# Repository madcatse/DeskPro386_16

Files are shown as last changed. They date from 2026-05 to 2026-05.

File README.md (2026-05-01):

# DeskPro386_16
Compaq DeskPro 386/16 KiCad Schematic and PLD files

The Compaq DeskPro 386 was one of the first 80386/i386 PC Compatable computers.
It used mainly standard components found in the PC and PC-XT and used 14 
basic 20 and 24 pin Programmable Logic Devices (PLDS).
Later DeskPro 386 versions used VLSI 160+ pin chips unsuitable for use with breadboards.

Internal Compaq Design documents have been made available on Archive.org which
not only include more recent schematics than the original DeskPro 386/16 Technical Guide,
but also include the PLD Logic Rules and test vectors for all the chips in the PALASM language.

PALASM can be converted into CUPL for use with WinCUPL/II and modern ATF16V8B and ATF22V10C PLDs.

Compaq DeskPro 386/16 Technical Guide https://archive.org/details/compaq-desk-pro-386-technical-reference-guide-vol-1-1986-09
COmpaq DeskPro 386/16 Internal Design Document https://archive.org/details/compaq-desk-pro-386-technical-reference-guide-vol-1-1986-09

## KiCad Schematics
The Internal Design Document schematics have been reproduced in KiCad 10.
I have layed them out in one big diagram so that related pages are closer together to make tracing labels easier.
I find decomposed diagrams over many pages more difficult to understand.
Feel free to make a copy and re-organise if you feel differently.

Many of the chip symbols have been created to match the DeskPro schematics (DP in name) in the Breadboarding Symbol library (Breadboarding.kicad_sym).
You will need to configure the path to this library after opening the Project.

Use Preferences | Manage Symbol Libraries... then select the "Project Specific Libraries" tab
Select the path to the Breadboarding.kicad_sym file downloaded from GitHub.

Note many of the DP symbols have the power pins removed as this is what the DeskPro schematics did.
If you try to use these symbols for making a PCB be aware of the missing power pins and decoupling capacitors.

Symbols with BB in the name tend to match the physical pin layout so that the schematic can also be used for laying out breadboard designs.
The layout dimensions are very large (almost twice as big as A0 paper size) at 40" x 70".
PDF readers may have problems dealing with the schematic.

## Programmable Logic Definitions
There are two versions of the Internal Design Document, text mode and photo mode.
Generally I have used text mode to convert the content but sometimes photo mode is better.
The main issues in converting the logic definitions have been confusions between numeric 0 and letter O and letter l and numeric 1.
The test vectors have required quite a lot of massaging as PDF does not make it easy to copy the content due to it sometimes arranging text blocks in columns.
The PALASM folder has the text copies of the original PDF document in their original format (and with original typos and spelling mistakes).
The file extension .ASM is used as this is the recognised file extension for the CUPL 2.0 PTOC.EXE converter which converts PLDASM files into a .PLD logic definition and .SI simulation file.

THe ZIP file Logical_Devices_CUPL_v3.2b.zip contains an old version of CUPL (July 1990) which predates ATMEL/MicroChip and include the PTOC.EXE utility used to convert PALASM in CUPL format files.

More folders will be added with the .PLD logic definition and .SI simulation files as these are migrated and tested.

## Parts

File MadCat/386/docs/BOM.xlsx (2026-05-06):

Reference | Qty | Value | Аналог | Footprint | Datasheet
Конденсаторы
C100 | 1 | 10pF
C117 | 1 | 18pF
C1,C2,C60,C114 | 4 | 47pF
C97 | 1 | 0.001uF
C98,C101 | 2 | 0.047uF
C9,C19 | 2 | 10uF
Резисторы
R34,R35 | 2 | 22R
R8,R25,R26 | 3 | 30R
MRB4,RB4 | 2 | 33R |  | Resistor_THT:R_Array_SIP9 | http://www.vishay.com/docs/31509/csc.pdf
MRP1 | 1 | 33R
R37 | 1 | 51R
R44 | 1 | 60R
R31,R33,R36,R38 | 4 | 68R
R10,R13,R18,R28/9,R30,R42 | 6 | 180R
R3 | 1 | 270R
R5,R12,R16,R20,R21,R24 | 6 | 1K
MRP5,MRP7,MRP8,MRP9 | 4 | 4K7 |  | Resistor_THT:R_Array_SIP10 | http://www.vishay.com/docs/31509/csc.pdf
R4 | 1 | 4K7
MRP6 | 1 | 8K2 |  | Resistor_THT:R_Array_SIP11 | http://www.vishay.com/docs/31509/csc.pdf
R15,R22 | 2 | 8K2
RP3,RP4,RP5 | 3 | 8K2 |  | Resistor_THT:R_Array_SIP10 | http://www.vishay.com/docs/31509/csc.pdf
RP6,RP8 | 2 | 8K2 |  | Resistor_THT:R_Array_SIP9 | http://www.vishay.com/docs/31509/csc.pdf
R39,R40 | 2 | 10K
R14,R41,R999,R1000,RX1,RX2 | 6 | 20K
RP7 | 1 | 20K |  | Resistor_THT:R_Array_SIP10 | http://www.vishay.com/docs/31509/csc.pdf
R1 | 1 | 87K
R19 | 1 | 470K
R17 | 1 | 22M
R2 | 1 | 48K
Микросхемы
MU25,U71 | 2 | 74F00 | КР1531ЛА3 (https://radio-hobby.org/modules/analog/%D0%BA%D1%801531%D0%BB%D0%B03) |  | http://www.ti.com/lit/gpn/sn74ls00
MU9 | 1 | 74F04 | КР1531ЛН1 (https://radio-hobby.org/modules/analog/%D0%BA%D1%801531%D0%BB%D0%BD1) |  | http://www.ti.com/lit/gpn/sn74LS04
U73 | 1 | 74F08 | КР1531ЛИ1 |  | http://www.ti.com/lit/gpn/sn74LS08
U92 | 1 | 74F11 | КР1531ЛИ3 (https://radio-hobby.org/modules/analog/%D0%BA%D1%801531%D0%BB%D0%B83) |  | http://www.ti.com/lit/gpn/sn74LS11
MU3,MU19,MU24,MU50 | 4 | 74F32 | КР1531ЛЛ1 (https://radio-hobby.org/modules/analog/%D0%BA%D1%801531%D0%BB%D0%BB1) |  | http://www.ti.com/lit/gpn/sn74LS32
U69 | 1 | 74F74 | КР1531ТМ2 (https://radio-hobby.org/modules/analog/%D0%BA%D1%801531%D1%82%D0%BC2) | Package_DIP:DIP-28_W15.24mm | 74xx/74hc_hct74.pdf
U84 | 1 | 74F74BB | КР1531ТМ2 (https://radio-hobby.org/modules/analog/%D0%BA%D1%801531%D1%82%D0%BC2) |  | 74xx/74hc_hct74.pdf
MU2,U79,U82,U83 | 4 | 74F74 | КР1531ТМ2 (https://radio-hobby.org/modules/analog/%D0%BA%D1%801531%D1%82%D0%BC2) |  | 74xx/74hc_hct74.pdf
U12,U13,U14,U15,U112 | 5 | 2764 |  | Package_DIP:DIP-28_W15.24mm | http://ww1.microchip.com/downloads/en/DeviceDoc/11107M.pdf
U86 | 1 | 4069 | 1561ЛН4 (https://radio-hobby.org/modules/analog/1561%D0%BB%D0%BD4) |  | http://www.intersil.com/content/dam/Intersil/documents/cd40/cd4069ubms.pdf
U78 | 1 | 8042
U22,U23 | 2 | 8237A |  | Package_DIP:DIP-40_W15.24mm
U44,U45 | 2 | 8254 |  | Package_DIP:DIP-24_W15.24mm | http://www.scs.stanford.edu/10wi-cs140/pintos/specs/8254.pdf
MU15,MU16,MU17 | 3 | 74F158 | 1531КП18 (https://radio-hobby.org/modules/analog/1531%D0%BA%D0%BF18) |  | http://www.ti.com/lit/gpn/sn74LS158
MU21,MU74,U65,U74 | 4 | 74F175 | КР1531ТМ8 (https://radio-hobby.org/modules/analog/%D0%BA%D1%801531%D1%82%D0%BC8) |  | 74xx/74hc_hct74.pdf
U89 | 1 | 74F175BB | КР1531ТМ8 (https://radio-hobby.org/modules/analog/%D0%BA%D1%801531%D1%82%D0%BC8) |  | 74xx/74hc_hct74.pdf
U59 | 1 | 74F257BB | КР1531КП11 (https://radio-hobby.org/modules/analog/%D0%BA%D1%801531%D0%BA%D0%BF11) |  | http://www.ti.com/lit/gpn/sn74LS257
MU5,MU13 | 2 | 74F521 | КР1531СП2
MU11,MU12 | 2 | 74F573 |  |  | http://www.ti.com/lit/gpn/sn74LS573
MU26,MU30,MU36,MU42 | 4 | 74F657
MU31 | 1 | 51256-10 |  | Package_DIP:DIP-16_W7.62mm | https://minuszerodegrees.net/memory/41256/datasheet_HM50256.pdf
U54,U66 | 2 | 74ALS00 |  |  | http://www.ti.com/lit/gpn/sn74ls00
U88 | 1 | 74ALS02 |  |  | http://www.ti.com/lit/gpn/sn74ls02
U55 | 1 | 74ALS04 |  |  | http://www.ti.com/lit/gpn/sn74LS04
MU10,U53 | 2 | 74ALS08 |  |  | http://www.ti.com/lit/gpn/sn74LS08
MU1,MU8,U7,U61,U63,U67,U70,U72,U81,U90 | 10 | 74ALS74 |  |  | 74xx/74hc_hct74.pdf
U16 | 1 | 74ALS163 |  |  | http://www.ti.com/lit/gpn/sn74LS163
MU6,MU14,U9,U11,U19,U21,U24,U25,U34,U35 | 10 | 74ALS573 |  |  | http://www.ti.com/lit/gpn/sn74LS573
U91 | 1 | 74ALS1035 |  |  | www.ti.com/lit/ds/symlink/sn74ls07.pdf
MU22 | 1 | 74ALS29827DP
U75 | 1 | 74HC125 |  |  | http://www.ti.com/lit/gpn/sn74HC125
MU20,MU43 | 2 | 74LS20 |  |  | http://www.ti.com/lit/gpn/sn74LS20
U62 | 1 | 74LS51 |  |  | http://www.ti.com/lit/ds/symlink/sn74ls51.pdf
U47,U48 | 2 | 74LS125 |  |  | http://www.ti.com/lit/gpn/sn74LS125
U49 | 1 | 74LS138 |  |  | http://www.ti.com/lit/gpn/sn74LS138
U50 | 1 | 74LS175 |  |  | http://www.ti.com/lit/gpn/sn74LS175
U28 | 1 | 74LS243 |  |  | http://www.ti.com/lit/gpn/sn74LS243
MU54,U4,U26,U37,U40,U41,U51 | 7 | 74LS244 |  |  | http://www.ti.com/lit/ds/symlink/sn74ls244.pdf
U3,U8,U10,U17,U18,U20,U27,U33 | 8 | 74LS245 |  |  | http://www.ti.com/lit/gpn/sn74LS245
U57 | 1 | 74LS273 |  |  | http://www.ti.com/lit/gpn/sn74LS273
U5 | 1 | 74LS590 |  |  | http://www.ti.com/lit/gpn/sn74ls590
U30 | 1 | 74LS612 |  | Package_DIP:DIP-40_W15.24mm | http://www.ti.com/lit/ds/symlink/sn74ls244.pdf
U39 | 1 | 74LSA573 |  |  | http://www.ti.com/lit/gpn/sn74LS573
U1,U2 | 2 | 8259A-2 |  | Package_DIP:DIP-28_W15.24mm | http://pdos.csail.mit.edu/6.828/2005/readings/hardware/8259A.pdf
MU7,MU18,MU59,U29,U31,U32,U38,U46,U52,U64,U68 | 11 | ATF16V8B |  |  | www.ti.com/lit/ds/symlink/sn74ls07.pdf
U56,U58 | 2 | ATF22V10
U76 | 1 | I386DX_PGA
U77 | 1 | MC146818 |  | Package_DIP:DIP-24_W15.24mm
U6 | 1 | MXO45HS-3C-14.3M |  | MXO45HS3C25M1750 | https://datasheet.datasheetarchive.com/originals/distributors/Datasheets-DGA23/1439510.pdf
U85 | 1 | MXO45HS-3C-32M |  | MXO45HS3C32M0000 | https://datasheet.datasheetarchive.com/originals/distributors/Datasheets-DGA23/1439510.pdf
U93 | 1 | SN75477 |  |  | https://www.ti.com/lit/gpn/SN75477
Коннекторы
J118 | 1 | BATTERY
J102 | 1 | Bus_ISA_16bit |  |  | https://en.wikipedia.org/wiki/Industry_Standard_Architecture
E123,ER1,ER2 | 3 | Conn_01x09_Pin
P101 | 1 | Conn_01x80_Pin_Memory_Board
J116 | 1 | KEYBOARD
H2 | 1 | KEYLOCK
J115 | 1 | SPEAKER
J101 | 1 | 32 Bit Mem Connector
Разное
Y2 | 1 | 32.76KHz
CR1,CR2,CR3 | 3 | 1N914 |  | Diode_THT:D_DO-35_SOD27_P7.62mm_Horizontal | http://www.vishay.com/docs/85622/1n914.pdf
L1,L2,L3,L4,L6 | 5 | FerriteBead
F2 | 1 | F 5A
SW1 | 1 | SW_DIP_x08
Q1 | 1 | TL431LP |  | Package_TO_SOT_THT:TO-92_Inline | http://www.ti.com/lit/ds/symlink/tl431.pdf

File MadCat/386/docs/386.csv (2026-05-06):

Reference | Qty | Value | DNP | Exclude from BOM | Exclude from Board | Footprint | Datasheet
C100 | 1 | 10pF
C117 | 1 | 18pF
C1,C2,C60,C114 | 4 | 47pF
C97 | 1 | 0.001uF
C98,C101 | 2 | 0.047uF
C9,C19 | 2 | 10uF
R34,R35 | 2 | 22R
R8,R25,R26 | 3 | 30R
J101 | 1 | 32 Bit Mem Connector
MRB4,RB4 | 2 | 33R |  |  |  | Resistor_THT:R_Array_SIP9 | http://www.vishay.com/docs/31509/csc.pdf
MRP1 | 1 | 33R
R37 | 1 | 51R
R44 | 1 | 60R
R31,R33,R36,R38 | 4 | 68R
MU25,U71 | 2 | 74F00 |  |  |  |  | http://www.ti.com/lit/gpn/sn74ls00
MU9 | 1 | 74F04 |  |  |  |  | http://www.ti.com/lit/gpn/sn74LS04
U73 | 1 | 74F08 |  |  |  |  | http://www.ti.com/lit/gpn/sn74LS08
U92 | 1 | 74F11 |  |  |  |  | http://www.ti.com/lit/gpn/sn74LS11
MU3,MU19,MU24,MU50 | 4 | 74F32 |  |  |  |  | http://www.ti.com/lit/gpn/sn74LS32
U69 | 1 | 74F74 |  |  |  | Package_DIP:DIP-28_W15.24mm | 74xx/74hc_hct74.pdf
U84 | 1 | 74F74BB |  |  |  |  | 74xx/74hc_hct74.pdf
MU2,U79,U82,U83 | 4 | 74F74 |  |  |  |  | 74xx/74hc_hct74.pdf
R10,R13,R18,R28/9,R30,R42 | 6 | 180R
R3 | 1 | 270R
R5,R12,R16,R20,R21,R24 | 6 | 1K
U12,U13,U14,U15,U112 | 5 | 2764 |  |  |  | Package_DIP:DIP-28_W15.24mm | http://ww1.microchip.com/downloads/en/DeviceDoc/11107M.pdf
U86 | 1 | 4069 |  |  |  |  | http://www.intersil.com/content/dam/Intersil/documents/cd40/cd4069ubms.pdf
MRP5,MRP7,MRP8,MRP9 | 4 | 4K7 |  |  |  | Resistor_THT:R_Array_SIP10 | http://www.vishay.com/docs/31509/csc.pdf
R4 | 1 | 4K7
U78 | 1 | 8042
MRP6 | 1 | 8K2 |  |  |  | Resistor_THT:R_Array_SIP11 | http://www.vishay.com/docs/31509/csc.pdf
R15,R22 | 2 | 8K2
RP3,RP4,RP5 | 3 | 8K2 |  |  |  | Resistor_THT:R_Array_SIP10 | http://www.vishay.com/docs/31509/csc.pdf
RP6,RP8 | 2 | 8K2 |  |  |  | Resistor_THT:R_Array_SIP9 | http://www.vishay.com/docs/31509/csc.pdf
U22,U23 | 2 | 8237A |  |  |  | Package_DIP:DIP-40_W15.24mm
U44,U45 | 2 | 8254 |  |  |  | Package_DIP:DIP-24_W15.24mm | http://www.scs.stanford.edu/10wi-cs140/pintos/specs/8254.pdf
R39,R40 | 2 | 10K
R14,R41,R999,R1000,RX1,RX2 | 6 | 20K
RP7 | 1 | 20K |  |  |  | Resistor_THT:R_Array_SIP10 | http://www.vishay.com/docs/31509/csc.pdf
Y2 | 1 | 32.76KHz
R2 | 1 | 48K
MU15,MU16,MU17 | 3 | 74F158 |  |  |  |  | http://www.ti.com/lit/gpn/sn74LS158
MU21,MU74,U65,U74 | 4 | 74F175 |  |  |  |  | 74xx/74hc_hct74.pdf
U89 | 1 | 74F175BB |  |  |  |  | 74xx/74hc_hct74.pdf
U59 | 1 | 74F257BB |  |  |  |  | http://www.ti.com/lit/gpn/sn74LS257
MU5,MU13 | 2 | 74F521
MU11,MU12 | 2 | 74F573 |  |  |  |  | http://www.ti.com/lit/gpn/sn74LS573
MU26,MU30,MU36,MU42 | 4 | 74F657
R1 | 1 | 87K
R19 | 1 | 470K
R17 | 1 | 22M
CR1,CR2,CR3 | 3 | 1N914 |  |  |  | Diode_THT:D_DO-35_SOD27_P7.62mm_Horizontal | http://www.vishay.com/docs/85622/1n914.pdf
MU31 | 1 | 51256-10 |  |  |  | Package_DIP:DIP-16_W7.62mm | https://minuszerodegrees.net/memory/41256/datasheet_HM50256.pdf
U54,U66 | 2 | 74ALS00 |  |  |  |  | http://www.ti.com/lit/gpn/sn74ls00
U88 | 1 | 74ALS02 |  |  |  |  | http://www.ti.com/lit/gpn/sn74ls02
U55 | 1 | 74ALS04 |  |  |  |  | http://www.ti.com/lit/gpn/sn74LS04
MU10,U53 | 2 | 74ALS08 |  |  |  |  | http://www.ti.com/lit/gpn/sn74LS08
MU1,MU8,U7,U61,U63,U67,U70,U72,U81,U90 | 10 | 74ALS74 |  |  |  |  | 74xx/74hc_hct74.pdf
U16 | 1 | 74ALS163 |  |  |  |  | http://www.ti.com/lit/gpn/sn74LS163
MU6,MU14,U9,U11,U19,U21,U24,U25,U34,U35 | 10 | 74ALS573 |  |  |  |  | http://www.ti.com/lit/gpn/sn74LS573
U91 | 1 | 74ALS1035 |  |  |  |  | www.ti.com/lit/ds/symlink/sn74ls07.pdf
MU22 | 1 | 74ALS29827DP
U75 | 1 | 74HC125 |  |  |  |  | http://www.ti.com/lit/gpn/sn74HC125
MU20,MU43 | 2 | 74LS20 |  |  |  |  | http://www.ti.com/lit/gpn/sn74LS20
U62 | 1 | 74LS51 |  |  |  |  | http://www.ti.com/lit/ds/symlink/sn74ls51.pdf
U47,U48 | 2 | 74LS125 |  |  |  |  | http://www.ti.com/lit/gpn/sn74LS125
U49 | 1 | 74LS138 |  |  |  |  | http://www.ti.com/lit/gpn/sn74LS138
U50 | 1 | 74LS175 |  |  |  |  | http://www.ti.com/lit/gpn/sn74LS175
U28 | 1 | 74LS243 |  |  |  |  | http://www.ti.com/lit/gpn/sn74LS243
MU54,U4,U26,U37,U40,U41,U51 | 7 | 74LS244 |  |  |  |  | http://www.ti.com/lit/ds/symlink/sn74ls244.pdf
U3,U8,U10,U17,U18,U20,U27,U33 | 8 | 74LS245 |  |  |  |  | http://www.ti.com/lit/gpn/sn74LS245
U57 | 1 | 74LS273 |  |  |  |  | http://www.ti.com/lit/gpn/sn74LS273
U5 | 1 | 74LS590 |  |  |  |  | http://www.ti.com/lit/gpn/sn74ls590
U30 | 1 | 74LS612 |  |  |  | Package_DIP:DIP-40_W15.24mm | http://www.ti.com/lit/ds/symlink/sn74ls244.pdf
U39 | 1 | 74LSA573 |  |  |  |  | http://www.ti.com/lit/gpn/sn74LS573
U1,U2 | 2 | 8259A-2 |  |  |  | Package_DIP:DIP-28_W15.24mm | http://pdos.csail.mit.edu/6.828/2005/readings/hardware/8259A.pdf
MU7,MU18,MU59,U29,U31,U32,U38,U46,U52,U64,U68 | 11 | ATF16V8B |  |  |  |  | www.ti.com/lit/ds/symlink/sn74ls07.pdf
U56,U58 | 2 | ATF22V10
J118 | 1 | BATTERY
J102 | 1 | Bus_ISA_16bit |  |  |  |  | https://en.wikipedia.org/wiki/Industry_Standard_Architecture
E123,ER1,ER2 | 3 | Conn_01x09_Pin
P101 | 1 | Conn_01x80_Pin_Memory_Board
F2 | 1 | F 5A
L1,L2,L3,L4,L6 | 5 | FerriteBead
U76 | 1 | I386DX_PGA
J116 | 1 | KEYBOARD
H2 | 1 | KEYLOCK
U77 | 1 | MC146818 |  |  |  | Package_DIP:DIP-24_W15.24mm
U6 | 1 | MXO45HS-3C-14.3M |  |  |  | MXO45HS3C25M1750 | https://datasheet.datasheetarchive.com/originals/distributors/Datasheets-DGA23/1439510.pdf
U85 | 1 | MXO45HS-3C-32M |  |  |  | MXO45HS3C32M0000 | https://datasheet.datasheetarchive.com/originals/distributors/Datasheets-DGA23/1439510.pdf
U93 | 1 | SN75477 |  |  |  |  | https://www.ti.com/lit/gpn/SN75477
J115 | 1 | SPEAKER
SW1 | 1 | SW_DIP_x08
Q1 | 1 | TL431LP |  |  |  | Package_TO_SOT_THT:TO-92_Inline | http://www.ti.com/lit/ds/symlink/tl431.pdf

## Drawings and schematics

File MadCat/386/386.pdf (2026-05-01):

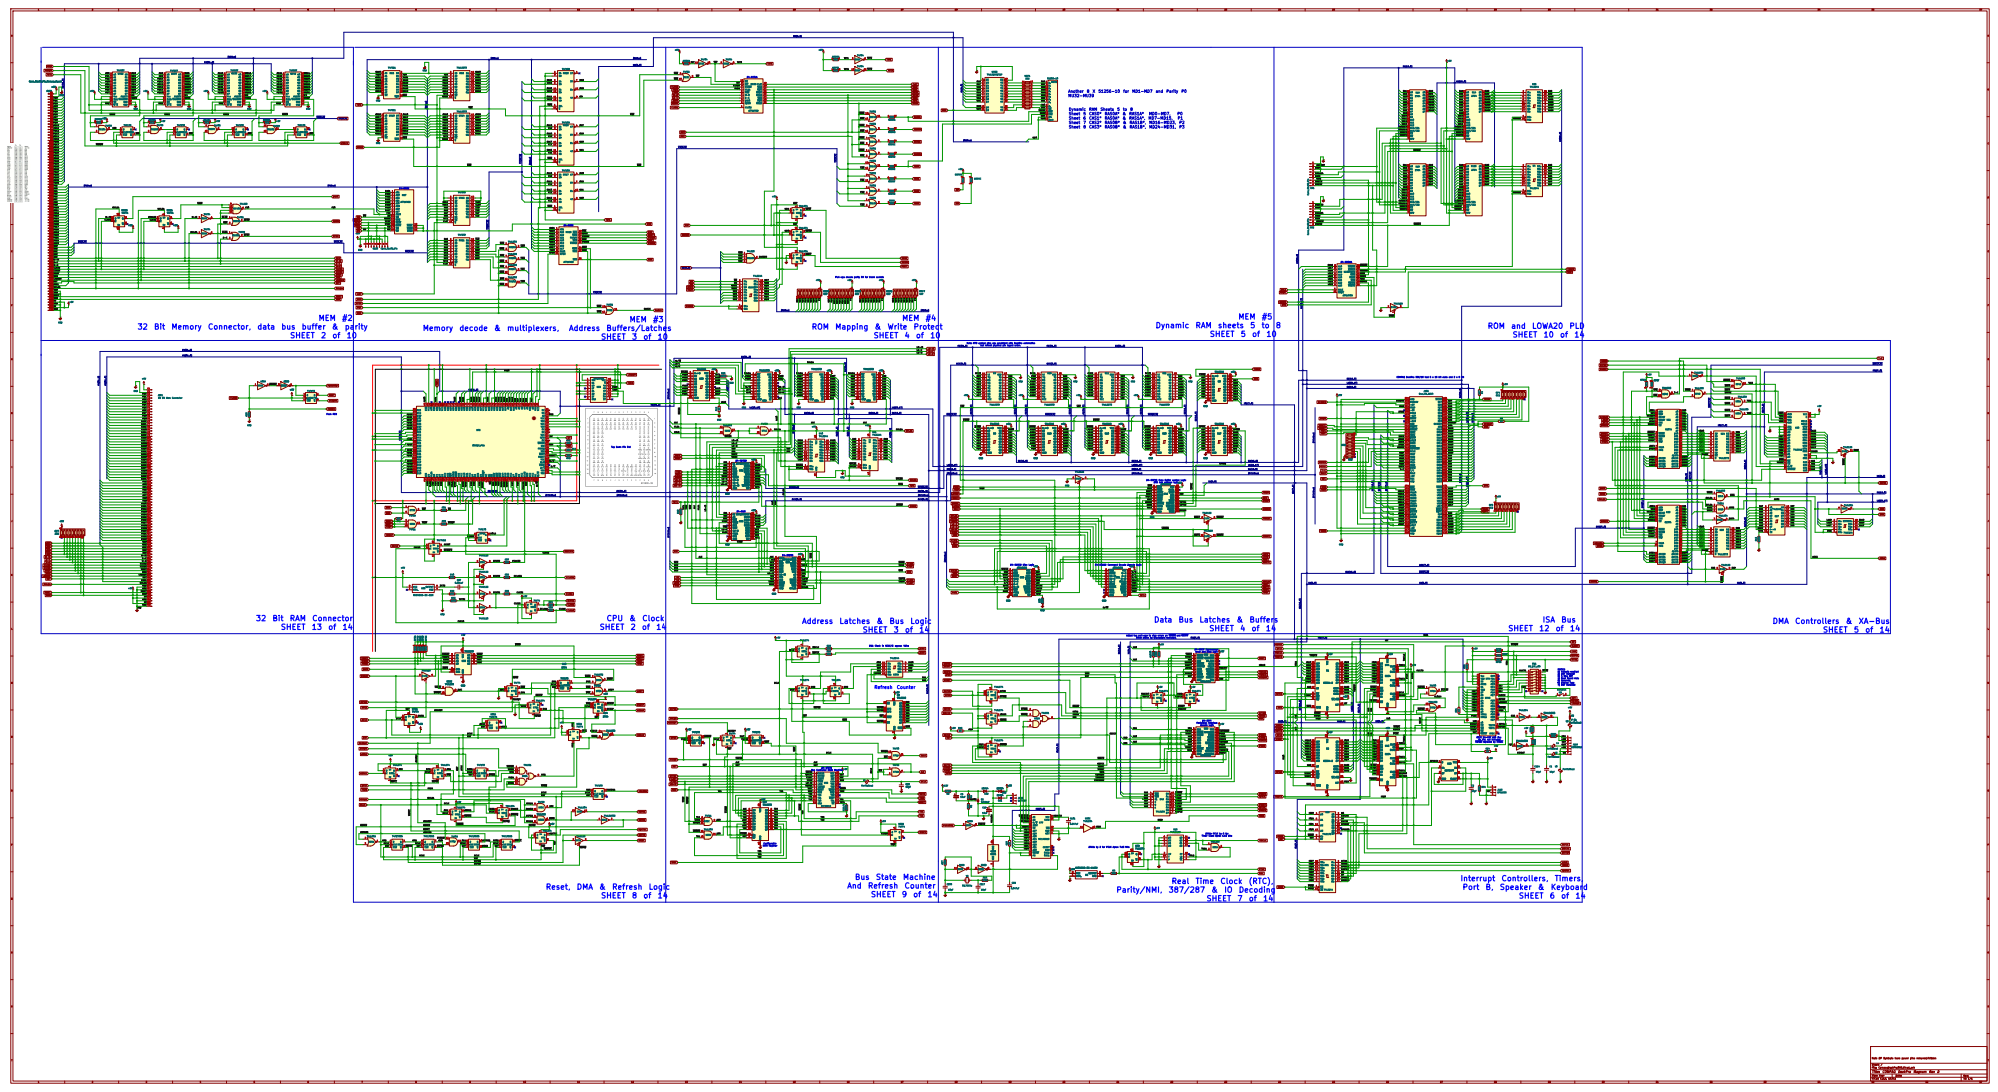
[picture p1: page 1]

KEYCS PPICS REFCK ONESHTDDIRQ

CLAST LM-IO MYCYC

Note DP Symbols have power pins removed/hidden

Sheet: /
File: CompaqDeskPro386.kicad_sch
Title: COMPAQ DeskPro Magnum Rev D

Size: User | Rev:
KiCad E.D.A. 10.0.1 | Id: 1/1
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

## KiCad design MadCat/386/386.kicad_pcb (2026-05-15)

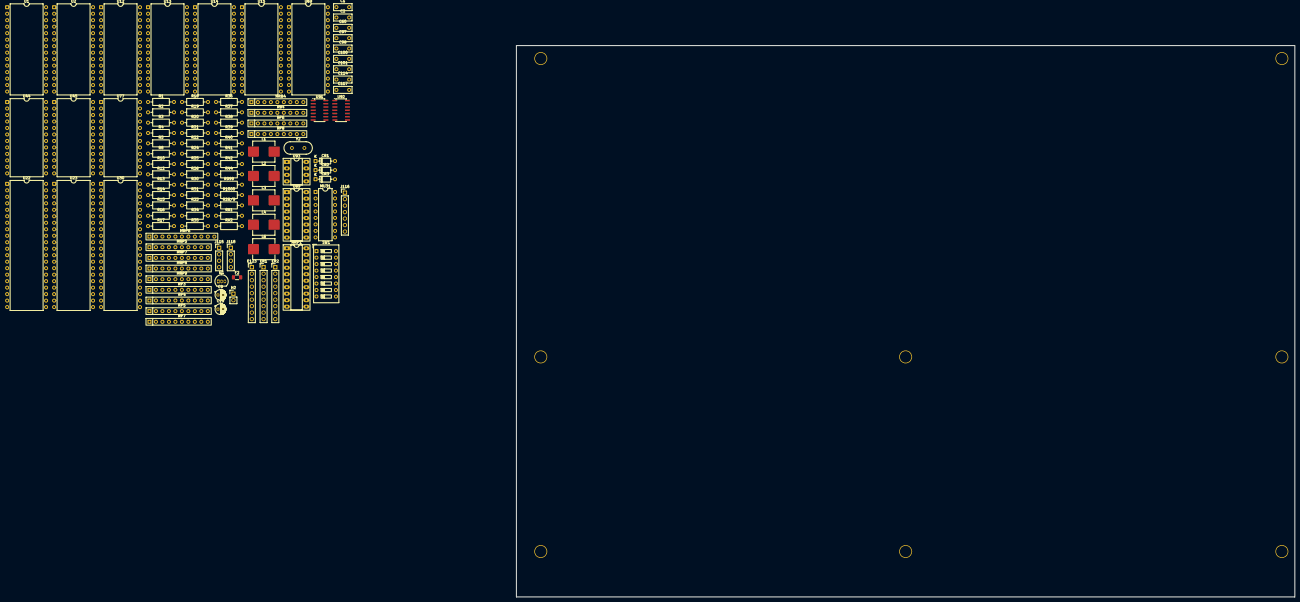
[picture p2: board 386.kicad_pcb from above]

Board: 2 copper layers, 304.8 x 215.9 mm, 109 parts (0 on the bottom side), 143 nets, no tracks yet.

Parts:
C1, C2, C60, C114: 47pF; C_Disc_D7.0mm_W2.5mm_P5.00mm
C9, C19: 10uF; CP_Radial_D4.0mm_P2.00mm
C97: 0.001uF; C_Disc_D7.0mm_W2.5mm_P5.00mm
C98, C101: 0.047uF; C_Disc_D7.0mm_W2.5mm_P5.00mm
C100: 10pF; C_Disc_D7.0mm_W2.5mm_P5.00mm
C117: 18pF; C_Disc_D7.0mm_W2.5mm_P5.00mm
CR1, CR2, CR3: 1N914; D_DO-35_SOD27_P7.62mm_Horizontal
E123: Conn_01x09_Pin; PinHeader_1x09_P2.54mm_Vertical
ER1, ER2: Conn_01x09_Pin; PinHeader_1x09_P2.54mm_Vertical
F2: F 5A; Fuse_1206_3216Metric
H1, H2#2, H3, H5, H6, H7, H8, H9: HOLE1; HOLE
H2: KEYLOCK; PinHeader_1x02_P2.54mm_Vertical
J115: SPEAKER; PinHeader_1x04_P2.54mm_Vertical
J116: KEYBOARD; PinHeader_1x07_P2.54mm_Vertical
J118: BATTERY; PinHeader_1x04_P2.54mm_Vertical
L1, L2, L3, L4, L6: FerriteBead; L_Panasonic_PCC-M0850M
MRB4: 33R; R_Array_SIP9
MRP1: 33R; DIP-20_W7.62mm_Socket_LongPads
MRP5, MRP7, MRP8, MRP9: 4K7; R_Array_SIP10
MRP6: 8K2; R_Array_SIP11
MU31: 51256-10; DIP-16_W7.62mm
Q1: TL431LP; TO-92_Inline
R1: 87K; R_Axial_DIN0207_L6.3mm_D2.5mm_P10.16mm_Horizontal
R2: 48K; R_Axial_DIN0207_L6.3mm_D2.5mm_P10.16mm_Horizontal
R3: 270R; R_Axial_DIN0207_L6.3mm_D2.5mm_P10.16mm_Horizontal
R4: 4K7; R_Axial_DIN0207_L6.3mm_D2.5mm_P10.16mm_Horizontal
R5, R12, R16, R20, R21, R24: 1K; R_Axial_DIN0207_L6.3mm_D2.5mm_P10.16mm_Horizontal
R8, R25, R26: 30R; R_Axial_DIN0207_L6.3mm_D2.5mm_P10.16mm_Horizontal
R10, R13, R18, R28/9, R30, R42: 180R; R_Axial_DIN0207_L6.3mm_D2.5mm_P10.16mm_Horizontal
R14, R41, R999, R1000: 20K; R_Axial_DIN0207_L6.3mm_D2.5mm_P10.16mm_Horizontal
R15, R22: 8K2; R_Axial_DIN0207_L6.3mm_D2.5mm_P10.16mm_Horizontal
R17: 22M; R_Axial_DIN0207_L6.3mm_D2.5mm_P10.16mm_Horizontal
R19: 470K; R_Axial_DIN0207_L6.3mm_D2.5mm_P10.16mm_Horizontal
R31, R33, R36, R38: 68R; R_Axial_DIN0207_L6.3mm_D2.5mm_P10.16mm_Horizontal
R34, R35: 22R; R_Axial_DIN0207_L6.3mm_D2.5mm_P10.16mm_Horizontal
R37: 51R; R_Axial_DIN0207_L6.3mm_D2.5mm_P10.16mm_Horizontal
R39, R40: 10K; R_Axial_DIN0207_L6.3mm_D2.5mm_P10.16mm_Horizontal
R44: 60R; R_Axial_DIN0207_L6.3mm_D2.5mm_P10.16mm_Horizontal
RB4: 33R; R_Array_SIP9
RP3, RP4, RP5: 8K2; R_Array_SIP10
RP6, RP8: 8K2; R_Array_SIP9
RP7: 20K; R_Array_SIP10
RX1, RX2: 20K; R_Axial_DIN0207_L6.3mm_D2.5mm_P10.16mm_Horizontal
SW1: SW_DIP_x08; SW_DIP_SPSTx08_Slide_9.78x22.5mm_W7.62mm_P2.54mm
U1, U2: 8259A-2; DIP-28_W15.24mm
U12, U13, U14, U15: 2764; DIP-28_W15.24mm
U22, U23: 8237A; DIP-40_W15.24mm
U30: 74LS612; DIP-40_W15.24mm
U44, U45: 8254; DIP-24_W15.24mm
U69: 74F74; DIP-28_W15.24mm
U77: MC146818; DIP-24_W15.24mm
U89: 74F175BB; DIP-16_W7.62mm_Socket_LongPads
U91: 74ALS1035; SOIC-14_3.9x8.7mm_P1.27mm
U92: 74F11; SOIC-14_3.9x8.7mm_P1.27mm
U93: SN75477; DIP-8_W7.62mm_Socket_LongPads
Y2: 32.76KHz; Crystal_HC49-U_Vertical

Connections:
+5V: CR2.2 (A), E123.1, E123.4, E123.7, F2.2, J115.1, MRP5.1 (common), MRP6.1 (R1), MRP7.1 (common), MRP8.1 (common), MRP9.1 (common), R4.1, R5.2, R16.1, R22.2, R24.1, R40.1, R41.1, R999.2, R1000.2, RP3.1 (common), RP4.1 (common), RP6.1 (R1), RP7.1 (common), RP8.1 (R1), RX1.2, RX2.2, U1.16 (~SP/~EN), U1.28 (VCC), U2.28 (VCC), U12.1 (VPP), U13.1 (VPP), U14.1 (VPP), U15.1 (VPP), U30.28 (C), U30.40 (VCC), U44.11 (G0), U44.14 (G1), U44.24 (VCC), U45.11 (G0), U45.14 (G1), U45.24 (VCC), U69.1 (~R), U69.4 (~S), U91.14 (VCC), U93.5 (CLAMP), U93.8 (VCC)
/+KB: J116.2, L6.1
/-KB: J116.5, J116.6, L3.2
/CAS0: U1.12 (CAS0), U2.12 (CAS0)
/CAS1: U1.13 (CAS1), U2.13 (CAS1)
/CAS2: U1.15 (CAS2), U2.15 (CAS2)
/DAE2: U23.9 (AEN), U92.4
/DRQ0: RP5.7 (R6), U22.19 (DREQ0)
/DRQ1: RP5.8 (R7), U22.18 (DREQ1)
/DRQ2: RP5.10 (R9), U22.17 (DREQ2)
/DRQ3: RP5.9 (R8), U22.16 (DREQ3)
/DRQ4: U22.10 (HRQ), U23.19 (DREQ0)
/DRQ5: RP5.6 (R5), U23.18 (DREQ1)
/DRQ6: RP5.5 (R4), U23.17 (DREQ2)
/DRQ7: RP5.4 (R3), U23.16 (DREQ3)
/FAILTM: SW1.1, U44.10 (OUT0)
/IOD0: U1.11 (D0), U2.11 (D0), U22.30 (DB0), U23.30 (DB0), U30.7 (D0), U44.8 (D0), U45.8 (D0), U77.4 (AD0)
/IOD1: U1.10 (D1), U2.10 (D1), U22.29 (DB1), U23.29 (DB1), U30.8 (D1), U44.7 (D1), U45.7 (D1), U77.5 (AD1)
/IOD2: U1.9 (D2), U2.9 (D2), U22.28 (DB2), U23.28 (DB2), U30.9 (D2), U44.6 (D2), U45.6 (D2), U77.6 (AD2)
/IOD3: U1.8 (D3), U2.8 (D3), U22.27 (DB3), U23.27 (DB3), U30.10 (D3), U44.5 (D3), U45.5 (D3), U77.7 (AD3)
/IOD4: U1.7 (D4), U2.7 (D4), U22.26 (DB4), U23.26 (DB4), U30.11 (D4), U44.4 (D4), U45.4 (D4), U77.8 (AD4)
/IOD5: U1.6 (D5), U2.6 (D5), U22.23 (DB5), U23.23 (DB5), U30.12 (D5), U44.3 (D5), U45.3 (D5), U77.9 (AD5)
/IOD6: U1.5 (D6), U2.5 (D6), U22.22 (DB6), U23.22 (DB6), U30.29 (D6), U44.2 (D6), U45.2 (D6), U77.10 (AD6)
/IOD7: U1.4 (D7), U2.4 (D7), U22.21 (DB7), U23.21 (DB7), U30.30 (D7), U44.1 (D7), U45.1 (D7), U77.11 (AD7)
/IRQ0: U1.18 (IR0), U45.10 (OUT0)
/IRQ2: U1.20 (IR2), U2.17 (INT)
/KEY: J115.3, J116.3
/KEYCLK: C1.2, L2.1, RP8.2 (R1.2), U91.8
/KEYDAT: C114.2, L4.1, RP8.3 (R2.2), U91.6
/KRS: J116.1, RP8.4 (R3.2)
/MA0: MRP1.2 (R2.1), MU31.5 (A_{0})
/MA1: MRP1.3 (R3.1), MU31.7 (A_{1})
/MA2: MRP1.4 (R4.1), MU31.6 (A_{2})
/MA3: MRP1.5 (R5.1), MU31.12 (A_{3})
/MA4: MRP1.6 (R6.1), MU31.11 (A_{4})
/MA5: MRP1.7 (R7.1), MU31.10 (A_{5})
/MA6: MRP1.8 (R8.1), MU31.13 (A_{6})
/MA7: MRP1.9 (R9.1), MU31.9 (A_{7})
/MA8: MRP1.10 (R10.1), MU31.1 (A_{8})
/MD0: MRP5.10 (R9), MRP7.10 (R9), MRP8.10 (R9), MU31.2 (Din), MU31.14 (Dout)
/MD1: MRP5.9 (R8), MRP7.9 (R8), MRP8.9 (R8)
/MD2: MRP5.8 (R7), MRP7.8 (R7), MRP8.8 (R7)
/MD3: MRP5.7 (R6), MRP7.7 (R6), MRP8.7 (R6)
/MD4: MRP5.6 (R5), MRP7.6 (R5), MRP8.6 (R5)
/MD5: MRP5.5 (R4), MRP7.5 (R4), MRP8.5 (R4)
/MD6: MRP5.4 (R3), MRP7.4 (R3), MRP8.4 (R3)
/MD7: MRP5.3 (R2), MRP7.3 (R2), MRP8.3 (R2)
/N9: J116.7, L2.2
/N10: J116.4, L4.2
/RD0: U12.11 (D0), U13.11 (D0)
/RD1: U12.12 (D1), U13.12 (D1)
/RD2: U12.13 (D2), U13.13 (D2)
/RD3: U12.15 (D3), U13.15 (D3)
/RD4: U12.16 (D4), U13.16 (D4)
/RD5: U12.17 (D5), U13.17 (D5)
/RD6: U12.18 (D6), U13.18 (D6)
/RD7: U12.19 (D7), U13.19 (D7)
/RD8: U14.11 (D0), U15.11 (D0)
/RD9: U14.12 (D1), U15.12 (D1)
/RD10: U14.13 (D2), U15.13 (D2)
/RD11: U14.15 (D3), U15.15 (D3)
/RD12: U14.16 (D4), U15.16 (D4)
/RD13: U14.17 (D5), U15.17 (D5)
/RD14: U14.18 (D6), U15.18 (D6)
/RD15: U14.19 (D7), U15.19 (D7)
/REND: U89.11 (~Q), U89.13 (D)
/RM1A13: ER1.2, U13.26 (A13/CS1), U15.26 (A13/CS1)
/RM1A14: ER1.5, U13.27 (A14/CS2), U15.27 (A14/CS2)
/RM2A13: ER2.2, U12.26 (A13/CS1), U14.26 (A13/CS1)
/RM2A14: ER2.5, U12.27 (A14/CS2), U14.27 (A14/CS2)
/RRQ: U89.2 (Q), U89.5 (D)
/SA1: U12.10 (A0), U13.10 (A0), U14.10 (A0), U15.10 (A0)
/SA2: U12.9 (A1), U13.9 (A1), U14.9 (A1), U15.9 (A1)
/SA3: U12.8 (A2), U13.8 (A2), U14.8 (A2), U15.8 (A2)
/SA4: U12.7 (A3), U13.7 (A3), U14.7 (A3), U15.7 (A3)
/SA5: U12.6 (A4), U13.6 (A4), U14.6 (A4), U15.6 (A4)
/SA6: U12.5 (A5), U13.5 (A5), U14.5 (A5), U15.5 (A5)
/SA7: U12.4 (A6), U13.4 (A6), U14.4 (A6), U15.4 (A6)
/SA8: U12.3 (A7), U13.3 (A7), U14.3 (A7), U15.3 (A7)
/SA9: U12.25 (A8), U13.25 (A8), U14.25 (A8), U15.25 (A8)
/SA10: U12.24 (A9), U13.24 (A9), U14.24 (A9), U15.24 (A9)
/SA11: U12.21 (A10), U13.21 (A10), U14.21 (A10), U15.21 (A10)
/SA12: U12.23 (A11), U13.23 (A11), U14.23 (A11), U15.23 (A11)
/SA13: U12.2 (A12), U13.2 (A12), U14.2 (A12), U15.2 (A12)
/SA14: ER1.3, ER2.3
/SA15: ER1.6, ER2.6
/SPKRCK: U45.17 (OUT2), U93.1 (S)
/SPKRDT: U93.2 (1A), U93.7 (2A)
/V2P5R: C9.2, Q1.1 (REF), R1.1, R2.2
/V5CMOS: C19.1, C101.2, CR1.1 (K), CR2.1 (K), CR3.1 (K), R20.2, U77.20 (CKFS), U77.24 (VCC)
/XA0: U1.27 (A0), U2.27 (A0), U22.32 (A0), U30.36 (RS0), U44.19 (A0), U45.19 (A0)
/XA1: U22.33 (A1), U23.32 (A0), U30.38 (RS1), U44.20 (A1), U45.20 (A1)
/XA2: U22.34 (A2), U23.33 (A1), U30.1 (RS2)
/XA3: U22.35 (A3), U23.34 (A2), U30.3 (RS3)
/XA4: U22.37 (A4), U23.35 (A3)
/XA5: U22.38 (A5), U23.37 (A4)
/XA6: U22.39 (A6), U23.38 (A5)
/XA7: U22.40 (A7), U23.39 (A6)
/ZCK32: R38.1, U69.3 (C)
/ZCLK16: R35.1, U69.6 (~Q)
/~CMSCE: U77.13 (~CE), U77.16 (STBY)
/~DAK4: U23.25 (DACK0), U30.2 (MA3), U92.5
/~EP1: RP6.7 (R6.2), U22.36 (~EOP)
/~EP2: RP6.8 (R7.2), U23.36 (~EOP)
/~RM1CS: ER1.8, U13.20 (~CE), U15.20 (~CE)
/~RM1OE: ER1.9, U13.22 (~OE), U15.22 (~OE)
/~RM2CS: ER2.8, U12.20 (~CE), U14.20 (~CE)
/~RM2OE: ER2.9, U12.22 (~OE), U14.22 (~OE)
/~ROM: ER1.7, ER2.7
/~TRDY: R33.1, U92.12
<NO NET>: H2.2 (B), SW1.10, SW1.11, SW1.12, SW1.13, SW1.14, SW1.15
BCLK: C60.1, L1.2, U89.9 (CLK)
CKM: RP8.6 (R5.2), SW1.3
CLK16: R35.2, U69.2 (D)
DCLK: R25.2, U22.12 (CLK), U23.12 (CLK), U44.18 (CLK2)
DRDY: U22.6 (READY), U23.6 (READY)
GND: C1.1, C2.1, C19.2, C60.2, C98.1, C100.1, C101.1, C114.1, C117.1, E123.3, E123.6, E123.9, ER1.1, ER1.4, ER2.1, ER2.4, H1.1, H2#2.1, H3.1, H5.1, H6.1, H7.1, H8.1, H9.1, J115.2, J118.4, L3.1, Q1.2 (A), R1.2, R10.1, R12.1, R13.1, R14.2, R15.1, R18.1, R21.2, R28/9.2, R30.2, R39.1, R42.1, RP5.1 (common), U1.14 (GND), U2.14 (GND), U2.16 (~SP/~EN), U30.13 (~MM), U30.20 (GND), U30.31 (D8), U30.32 (D9), U30.33 (D10), U30.34 (D11), U44.12 (GND), U45.12 (GND), U77.1 (MOT), U77.12 (GND), U91.7 (GND), U93.4 (GND)
unnamed: C97.2, R39.2, R40.2
unnamed: C100.2, R17.1, Y2.1
unnamed: C117.2, R19.1, Y2.2
unnamed: CR1.2 (A), J118.1
unnamed: C9.1, CR3.2 (A), Q1.3 (K), R2.1, R3.1
unnamed: F2.1, L6.2
unnamed: J115.4, R44.1
unnamed: R17.2, R19.2
unnamed: C98.2, R20.1, U77.18 (~RESET), U77.22 (PS)
unnamed: C2.2, R44.2, U93.3 (1Y), U93.6 (2Y)
RESDRV: U22.13 (RESET), U23.13 (RESET)
TIMCLK: U44.9 (CLK0), U44.15 (CLK1), U45.9 (CLK0), U45.15 (CLK1), U45.18 (CLK2)
TST1: MRP6.9 (R8.2), R18.2
TST2: MRP6.10 (R9.2), R10.2
~CRDY: R41.2, U92.13
~DMRDC: RP6.2 (R1.2), U22.3 (~MEMR), U23.3 (~MEMR)
~HITIM: RP8.8 (R7.2), SW1.16
~INTA: U1.26 (~INTA), U2.26 (~INTA)
~MRDY: RP7.7 (R6), U92.1
~NCPIN: RP8.7 (R6.2), SW1.2
~RST: R24.2, U89.1 (~CLR)
~WE0: MRP1.1 (R1.1), MU31.3 (~WE)
~XIORC: RP6.4 (R3.2), U1.3 (~RD), U2.3 (~RD), U22.1 (~IOR), U23.1 (~IOR), U44.22 (~RD), U45.22 (~RD)
~XIOWC: RP6.3 (R2.2), U1.2 (~WR), U2.2 (~WR), U22.2 (~IOW), U23.2 (~IOW), U30.5 (~STROBE), U44.23 (~WR), U45.23 (~WR)
~XMWTC: RP6.5 (R4.2), U22.4 (~MEMW), U23.4 (~MEMW)
~ZCK16: R34.1, U69.5 (Q)
